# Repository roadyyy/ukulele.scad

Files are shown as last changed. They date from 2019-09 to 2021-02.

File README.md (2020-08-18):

# ukulele.scad
Easy to print and assemble ukulele that doesn't sound like crap )

Project page: https://www.thingiverse.com/thing:4389517
Sound sample here: https://youtu.be/leMtTsVdUpw

Wood fillament is recommended (I have not yet tried my successful version with PLA)

I decided to make a customizable ukulele design for easy 3d-printing and assembly.

There are a lot of parameters that can be customized like scale length, fret number, string gauges etc.

Any body and headstock shapes can be drawn in Inkscape (or whatever can export svg or dxf) and applied to the design with some corrections (variables like bodyPos are there to help with positioning of custom drawn deck designs)

Only non 3d printed things you need are strings and tuners

UPD: Many bugs discovered at initial print fixed. Added s superstrat shape. And guess what. It sounds surprisingly decent when printed with wood fillament

How to print one:
INSTRUCTIONS

You can either use the stl files from this project (if so, just skip to step 4) or get you hands a little dirty and customize the design or other parameters which I will cover below.

1. Open main.scad file and review or change the parameters to your preference. in the bottom of this file are module calls to render the ukulele.

2. draw your own shapes for body and headstock in inkscape (files also included). Try to get them positioned roughly like the ones provided. You can also position them in main.scad using coresponding params

3. When you are satisfied with the design scroll to the bottom of main.scad and comment all the part module calls and render and export them uncommenting lines one by one so you get all the parts as separate stl files. 

4. print it using following materiald and settings:
- Headstock - wood fillament 70% infill or more
- Neck - wood, 70% infill or more
- Body - wood, 100% infill
- Deck - wood, 100% infill
- Bridge - PLA or any, 100% infill
- Bridge Nut - pla, 100%
- fretboard - PLA or PA, 100%
- Dots - PLA, or any, 30%+ infill
5. snap all parts together and glue them with cyanoacrilate adhesive (superglue), except for bridge nut, no need to glue that one.
6. buy and install tuners
7. set up strings
8. tune it and play your favorite song

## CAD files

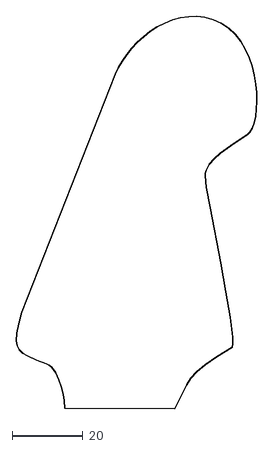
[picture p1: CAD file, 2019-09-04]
headstock1.dxf
67.8 x 110.5

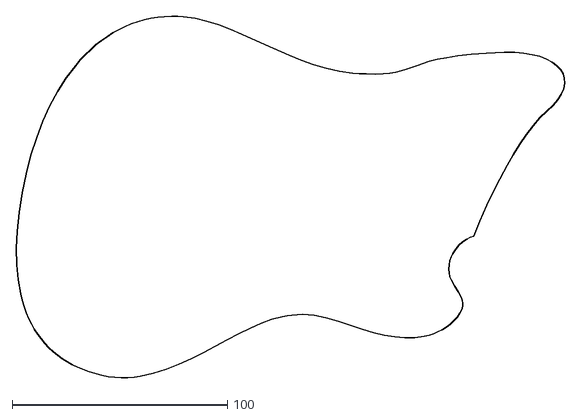
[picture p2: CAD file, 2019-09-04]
jt.dxf
254.6 x 167.8

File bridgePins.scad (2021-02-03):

module bridgePins (clr) {
    //positioning sockets
        translate([15,sbWall, neckL - scaleLength])
            rotate([90,0,0])
                cylinder (sbWall * 2, 2.5+clr/2, 2.5+clr/2);
        translate([-15, sbWall, neckL - scaleLength])
            rotate([90,0,0])
                cylinder (sbWall * 2, 2.5+clr/2, 2.5+clr/2);
}

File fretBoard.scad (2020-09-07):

module fretboard () {
    s = scaleLength;
    difference () {
        union () {
            rotate([90,0,0]) {

                translate([0,0, -fretBoardD]) 
                    linear_extrude(fretBoardD) 
                        hull () {
                            translate([-neckW2/2,0,0]) 
                                square([neckW2, 0.1]);
                            translate([-neckW1/2,neckL,0]) 
                                square([neckW1, 0.1]);
                        }
                
                // nut
                
                    translate([-neckW1/2, neckL, -fretBoardD-nutH]) 
                        difference () {
                            cube ([neckW1, nutL, fretBoardD+nutH]);
                            
                            translate([neckW1/2-stringsWidthNut/2,nutL, nutH - stringHeight]) 
                                rotate([90,0,0]) 
                                    translate([0,0, -1])
                                        linear_extrude(nutL+2) hull () {
                                            circle (s1g/2 + clearance);
                                            translate([0, -nutH, 0]) circle (s1g/2);
                                        }
                            translate([neckW1/2-stringsWidthNut/2+stringsWidthNut/3,nutL,nutH - stringHeight]) 
                                rotate([90,0,0]) 
                                    translate([0,0, -1])
                                        linear_extrude(nutL+2) hull () {
                                            circle (s2g/2 + clearance);
                                            translate([0, -nutH, 0]) circle (s2g/2);
                                        }
                            translate([neckW1/2-stringsWidthNut/2+stringsWidthNut/3*2,nutL,nutH - stringHeight]) 
                                rotate([90,0,0]) 
                                    translate([0,0, -1])
                                        linear_extrude(nutL+2) hull () {
                                            circle (s3g/2 + clearance);
                                            translate([0, -nutH, 0]) circle (s3g/2);
                                        }
                            translate([neckW1/2+stringsWidthNut/2,nutL,nutH - stringHeight]) 
                                rotate([90,0,0]) 
                                    translate([0,0, -1])
                                        linear_extrude(nutL+2) hull () {
                                            circle (s4g/2 + clearance);
                                            translate([0, -nutH, 0]) circle (s4g/2);
                                        }
                        }
            // /rotate
            }

            // lets do the frets
            translate([0, fretBoardD, neckL]) {
                rotate ([-90,0,90]) {
                    for (n = [1:1:numFrets]) {
                        translate([0, s-(s/(pow(2,(n/12)))), 0]) {

                            difference () {
                                cylinder (neckW1 + (neckW2-neckW1)/neckL*(s-(s/(pow(2,(n/12))))), fretH/2, fretH/2, true);
                                translate([0,-fretH/2, -(neckW1 + (neckW2-neckW1)/neckL*(s-(s/(pow(2,(n/12))))))/2])
                                    rotate([0,45,0])
                                        cube([fretH, fretH, fretH]);
                                translate([0,-fretH/2, (neckW1 + (neckW2-neckW1)/neckL*(s-(s/(pow(2,(n/12))))))/2])
                                    rotate([0,45,0])
                                        cube([fretH, fretH, fretH]);
                            }
                        }
                    }
                }
            }
        }
        // fret marks
        fretmarks(1, 0);
    }
}

module fretmarks (margin, clr) {
    s = scaleLength;
    for (n = fm) {
        translate([0,0, neckL - (s-(s/(pow(2,((n-1)/12))))) - (((s-(s/(pow(2,((n)/12))))) - (s-(s/(pow(2,((n-1)/12)))))) / 2)])
            rotate([-90,0,0]) cylinder (fretBoardD+margin, fretMark-clr, fretMark-clr);
    }
    // double mark
    for (n = fm2) {
        translate([neckW2/2-10,0, neckL - (s-(s/(pow(2,((n-1)/12))))) - (((s-(s/(pow(2,(n/12))))) - (s-(s/(pow(2,((n-1)/12)))))) / 2)])
            rotate([-90,0,0]) cylinder (fretBoardD+margin, fretMark-clr, fretMark-clr);
        translate([-neckW2/2+10,0, neckL - (s-(s/(pow(2,((n-1)/12))))) - (((s-(s/(pow(2,(n/12))))) - (s-(s/(pow(2,((n-1)/12)))))) / 2)])
            rotate([-90,0,0]) cylinder (fretBoardD+margin, fretMark-clr, fretMark-clr);
    }
}

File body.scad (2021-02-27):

module body () {
    
    difference () {
        
        union () {
            // outer
            difference () {
                translate([0, -bodyTh-sbWall, bodyPos]) 
                    rotate([0, -90,-90])
                        linear_extrude(bodyTh+sbWall, convexity=10) 
                            resize([bodyResize, 0, 0]) 
                                import (file = bodyShape, convexity= 4);
                // inner
                translate([0, -bodyTh-.1-sbWall, bodyPos]) 
                    rotate([0, -90,-90]) 
                        linear_extrude(bodyTh+.1, convexity=10)
                            offset (-wall)
                                resize([bodyResize, 0, 0])
                                    import (file = bodyShape, convexity= 4);
                
                // soundhole
                if (!customHole) {
                    translate([0,1,-holePos]) rotate([90,0,0]) cylinder(wall+2, hole, hole);
                } else {
                    translate([0,1,-holePos]) rotate([0,-90,90]) linear_extrude(wall+2) import(file = shShape);
                }
                
                //bridge positioning holes
                translate([0, -1, 0]) bridgePins(clearance);
            }

            // back glue points and reinforcement
            translate([0, -bodyTh,0]) {
                difference () {
                    innerDeck(wall, 0);
                    innerDeck(-4, 0.1);
                }
            }
            // front reinforcement
            translate([0, -3-sbWall,0]) {
                difference () {
                    innerDeck(wall, 0);
                    innerDeck(-3, 0.1);
                }
            }
            
            // socket insert
            intersection () {
                translate([0, -bodyTh, bodyPos]) 
                    rotate([0, -90,-90]) 
                        linear_extrude(bodyTh, convexity=10) 
                            resize([bodyResize, 0, 0]) 
                                import (file = bodyShape, convexity= 4);
                translate([-socketW/2,0, 5]) 
                    rotate([90,0,0]) 
                        linear_extrude(bodyTh, convexity=10) 
                            offset(clearance+wall) 
                                square ([socketW, neckL]);
            }
            // bridge supports
            intersection() {
                translate([-1.5 + neckW2/2, -bodyTh, neckL-scaleLength-50])
                    difference () {
                        translate([0,0, -30]) cube ([3, bodyTh, 90]);
                        translate([-.1, 0, bodyTh+sbWall + 10]) rotate([0, 90, 0]) cylinder(3.2, bodyTh-10, bodyTh-10);
                    }

                translate([0, -bodyTh, bodyPos]) 
                    rotate([0, -90,-90]) 
                        linear_extrude(bodyTh, convexity=10) 
                            resize([bodyResize, 0, 0]) 
                                import (file = bodyShape, convexity= 4);
            }

            intersection() {
                translate([-1.5 - neckW2/2,-bodyTh, neckL-scaleLength-50]) 
                    difference () {
                        translate([0,0, -30])cube ([3, bodyTh, 90]);
                        translate([-.1, 0, bodyTh+sbWall + 10]) rotate([0, 90, 0]) cylinder(3.2, bodyTh-10, bodyTh-10);
                    }

                translate([0, -bodyTh, bodyPos]) 
                    rotate([0, -90,-90]) 
                        linear_extrude(bodyTh, convexity=10) 
                            resize([bodyResize, 0, 0]) 
                                import (file = bodyShape, convexity= 4);
            }
        }
        // socket
        translate([0,clearance,neckL - socketDistance-socketL-clearance])
            difference() {
                translate([(-socketW-2*clearance)/2,-socketD-2*clearance,0])
                    cube ([socketW+clearance*2, socketD+2*clearance, socketL+socketD-clearance]);
                translate([0,-socketD/2, 0]) 
                    translate([-socketW/2, socketD/2, socketCylinder * 1.5+clearance]) 
                        rotate([90, 0, 0]) 
                            cylinder (socketD+2, socketCylinder-clearance, socketCylinder-clearance);
                translate([0,-socketD/2, 0]) 
                    translate([socketW/2, socketD/2, socketCylinder * 1.5+clearance]) 
                        rotate([90, 0, 0]) 
                            cylinder (socketD+2, socketCylinder-clearance, socketCylinder-clearance);
            }
    }
}


module deck () {
    // deck front
    translate([0, -bodyTh-sbWall]) mirror ([0, 1, 0])
    union () {
        difference () {
            translate([0, -sbWall, bodyPos])
                rotate([0, -90,-90]) 
                    linear_extrude(sbWall, convexity=10)
                        offset(-wall-(clearance)) resize([bodyResize, 0, 0])
                            import (file = bodyShape, convexity= 4);
            
           
        }
    }
}

module innerDeck (offset, offsetH) {
    translate([0, -offsetH, bodyPos])
        rotate([0, -90,-90]) 
            linear_extrude(3 + offsetH * 2, convexity=10)
                offset (-wall-clearance+offset)
                    resize([bodyResize, 0, 0])
                        import (file = bodyShape, convexity= 4);
    
}

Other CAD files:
bridge.scad
headstock.scad
jt.scad
main.scad
neck.scad

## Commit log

2019-09-21 neck length fix to fit nut neck to be cut where it shoud body socket - removed exrtra length
    [body.scad, fretBoard.scad, headstock.scad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]
2019-09-21 rearrange vars, comments
    [main.scad]
2019-09-21 headstock holes for tuners
    [headstock.scad, main.scad]
2019-09-21 round frets
    [fretBoard.scad]
2019-09-21 string cutouts
    [fretBoard.scad, main.scad]
2019-10-17 ready to test print
    [body.scad, bridge.scad, fretBoard.scad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]
2020-05-23 Fixed some body and socket clearance issues, separated bridge from the body, reverced body parts to look better on the assembly.
    [body.scad, bridge.scad, fretBoard.scad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]
2020-05-23 removed stls
    [jt0-h.stl, jt0-n.stl, jt0-и.stl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]
2020-08-08 extra design, body fixes
    [body.scad, headstock.scad, headstock1.dxf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]
2020-08-10 some clearance fixes after test print
    [body.scad, main.scad]
2020-08-18 various fixes
    [body.scad, bridge.scad, main.scad]
2020-09-05 carbon tube slot added bridge holes made smaller bridge support reinforced
    [body.scad, bridge.scad, main.scad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]
2020-09-07 carbon tube clearance added
    [fretBoard.scad, main.scad, neck.scad]
2021-02-03 bridge pins made separate
    [body.scad, bridge.scad, bridgePins.scad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]
2021-02-09 bridge and headstock fixes
    [body.scad, bridge.scad, headstock.scad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]
2021-02-27 added support for custom hole shape, some fixtures
    [body.scad, headstock.scad, main.scad]
